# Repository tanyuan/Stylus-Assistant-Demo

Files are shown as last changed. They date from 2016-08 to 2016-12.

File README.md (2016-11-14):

# Stylus Assistant: Designing Dynamic Constraints for Facilitating Stylus Inputs on Portable Displays

## Project Introduction
This work, Stylus Assistant, proposed two designs of actuator array system, **DynaFrame** and **DynaBase**, to realize dynamic physical constraints on portable displays for facilitating stylus input.

## DynaFrame

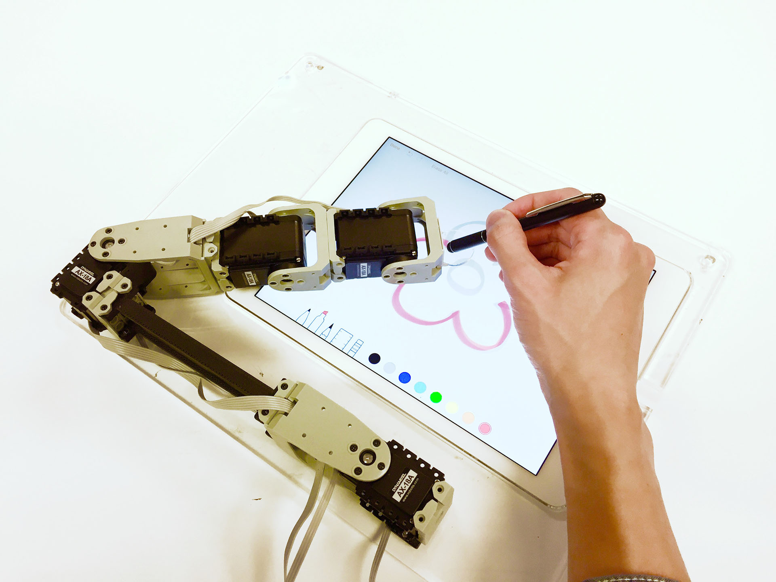
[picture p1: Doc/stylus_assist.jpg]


## User Interface

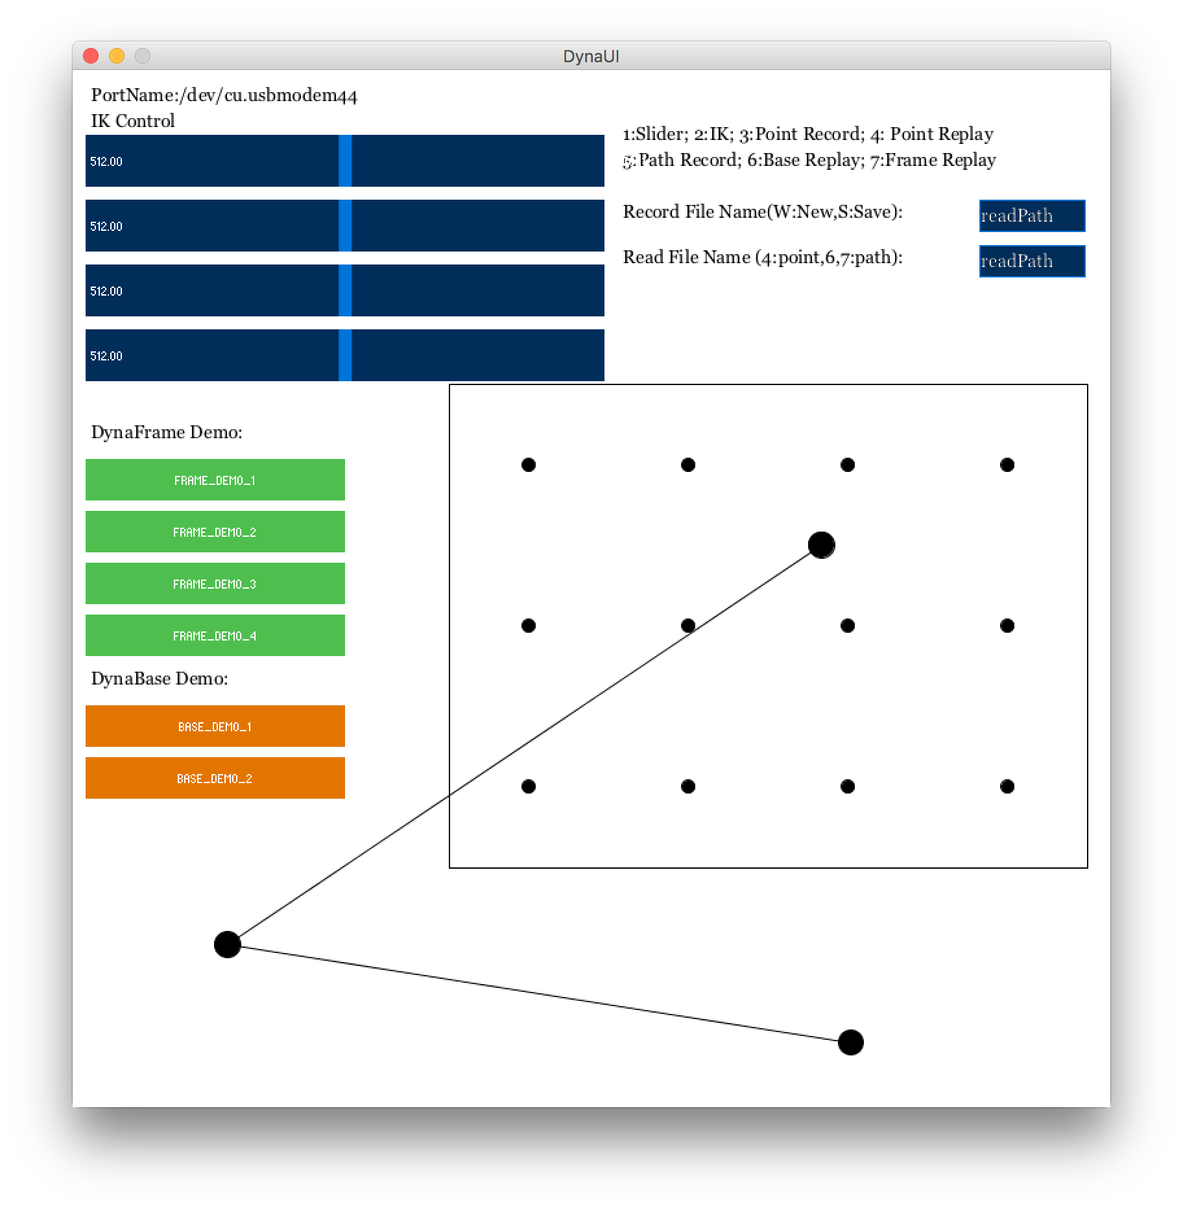
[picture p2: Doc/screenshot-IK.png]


## File Description
* **DynaArd** - Arduino Code
* **DynaUI** - Processing Code
* **Models** - SketchUp and Illustrator files
* **SetID** - Dynamixel AX-18A Motor ID Setting
* **Doc** - Documents

## Project Documents
* Original Version: [Google Doc](https://docs.google.com/document/d/1mkmDp4YyBh0SwKKhiSD5-HdVlsP8pnFafbvmv74smBk/edit?usp=sharing) / [PDF](Doc/StylusAssistantDocument.pdf)
* Demo Version: [Google Doc](https://docs.google.com/document/d/1DRZvKb9pZrIUMAFr76vTpBE7sWNrNrS9NaeW5d6-lQI/edit?usp=sharing)

## Author

Long-Fei Lin, National Taiwan University

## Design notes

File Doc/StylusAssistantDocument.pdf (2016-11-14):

# Stylus Assistant Instructions

## Modes

在硬體鏈接無誤后，Arduino的Code也上傳到Mega后，打開Processing。 這份Code包括7種不同的控制馬達的模式，通過按鍵盤上數字的1﹣7來切換：
1. Slider Control，左右移動滑塊可控制單個馬達，用以最初的Debug;
2. IK Control, 這時候按住滑鼠左鍵，移動滑鼠就可以控制馬達移動;
3. Points Record Control, 記錄單個點,一般用于實驗；
4. Points Replay Control, 回放單個點；
5. Path Record Control, 記錄畫筆的路徑；
6. DynaBase Path Replay, 用於DynaBase 路徑回放；
7. DynaFrame Path Replay, 用於Dyna Frame 路徑回放。

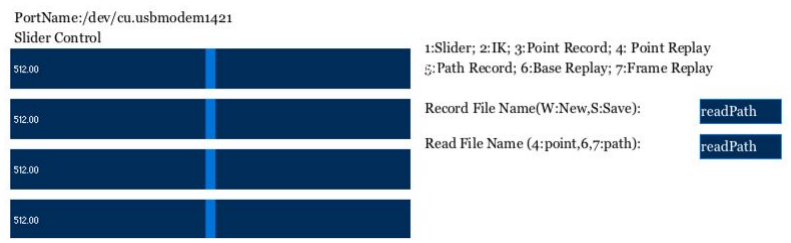
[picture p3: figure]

## Processing Setting

1. 首先確認Processing 的PortName為Arduino Mega (比如dev/cu.usbmodem1421)，否 則到Processing中的portName = Serial.list()[3] 中修改數字，數字參考Arduino菜單欄 Tools->Port， 從0開始數；
2. PortName 下方為7重模式的狀態欄，切換數字鍵1﹣7來更改；
3. 右邊兩個輸入框為文件名填寫，以保存與讀取相對應的路徑。

## Points Record and Replay

=== Points Record
1. 更改記錄文件的名稱 Record File Name；
2. 按數字‘3’，進入Points Record Mode；
3. 按‘w’新建一個一個txt檔案；
4. 點擊滑鼠到相對應的位置；按'n'記錄下一個點，重複該步驟；
5. 記錄結束后按's'保存文件，切記，否則文件為空。
=== Points Replay
1. 更改讀取文件的名稱Read File Name；
2. 按數字‘4’，進入Points Replay Mode；
3. 這時候馬達會直接開始跑到第一個點；
4. 按字母‘n’，可以走到下一個點；
5. 按字母’b’, 可以走回上一個點。

## Path Record and Replay

=== Path Record
1. 更改紀錄文件的名稱，Record File Name；
2. 按數字’5’, 進入Path Record Mode；
3. 按字母’w’，新建一個txt檔案；
4. 按住滑鼠左鍵，移動滑鼠來畫出所需要的路徑，在记录Frame的路徑都適合，每一個 筆劃結束和開始的時候，按住鼠標停頓1秒；
5. 畫完後按字母’s’，保存文件，切記，否則文件唯恐。
=== Points Replay
DynaBase與DynaFrame的回放操作步驟一致，但由於兩者的後3 4顆馬達的角度計算不同， 故回放模式不同，Base為6，Frame為7，不可混餚；
1. 更改回放文件的名稱，Read File Name;
2. 按下’6/7’後，開始回放剛才的路徑。

# Hardware Setting

## Reference

硬體的設置最早的參考是來源於這個鏈接，AX12A的原理與AX18A基本相同，這裡我們使用 的鏈接方式為Dynamixel Serial1
http://savageelectronics.blogspot.tw/2011/01/arduino-y-dynamixel-ax-12.html

## Hardware Lists

以下為物品清單，以及各個組件之間的連接方式，
如果是很多個馬達，就直接並聯馬達的pin腳。
- Arduino Mega 2560
- Dynamile AX18A
- Multiplexer 74LS241
- Resistance 10kΩ

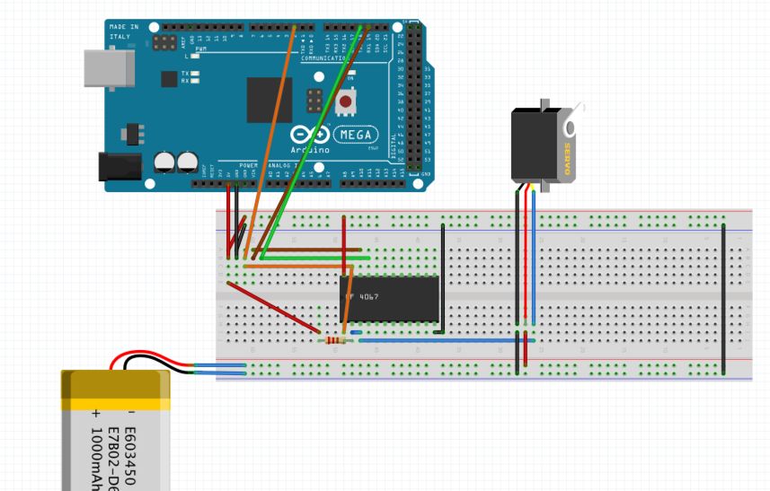
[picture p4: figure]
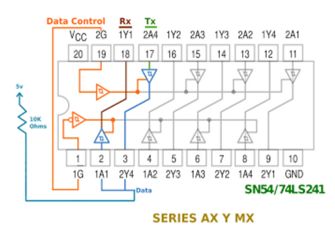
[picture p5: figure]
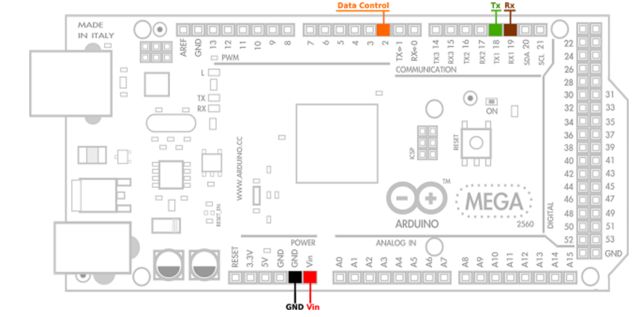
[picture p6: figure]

Multiplexer 74LS241 | Mega

# Software Setting

## Arduino

== Dynamixel Arduino Library Document http://austinlpalmer.com/Projects/Documentr/#/home
== Library Download, [DynamixelSerial1.zip] https://sourceforge.net/projects/dynamixelforarduino/files/?source=navbars

以下為Arduino控制Dyanmixel的Library，根據Document顯示，比較常用的幾個函數分別為
- setId (ID , newID )；因為會控制很多馬達，所以需要設置各個馬達的ID，出廠ID為1。 這裡需要注意的是，在為馬達設置完ID后，請再馬達上做上相對的記號，免得之後忘 記；
- ping(ID) 用來找馬達是否鏈接正確，1為找到，0為未找到；
- Dynamixel.moveSpeed(ID , Position, Speed) : ID為對應馬達的ID，Postion為馬達要 轉到的位置[0,1023]，Speed為馬達轉動的速度[0,1023];
- Dynamixel.move ( ID , Position) : ID為對應馬達的ID，Postion為馬達要轉到的位置 [0,1023]
- var = Dynamixel.readPosition(ID) ; 讀取馬達ID的當前位置

== Code Review
MOTORNUM 馬達的個數
motorRange[MOTORNUM][2] 馬達角度保護區間，放置數據傳輸錯誤，防止馬達角度超過一 定值，互相干擾卡在一起，保護馬達不會損壞
readEvent(Pos)：接受從Processing 那邊傳來的馬達角度
sendEvent(readPos): 將馬達當前的位置發送給Processing

## Processing

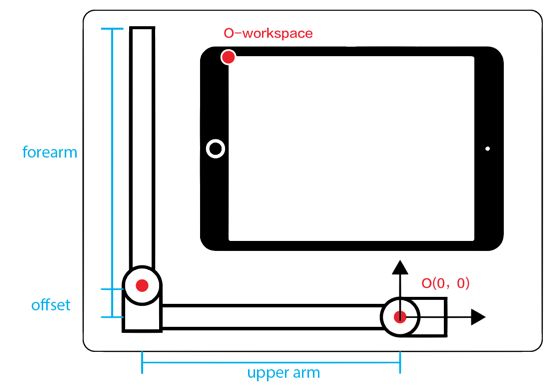
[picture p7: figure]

===Parameters Review
PVector screen = new PVector(19.7, 14.9); //螢幕的長寬長度 在計算IK的時候，會把Processing的座標系原點轉換到機械手臂根部，如圖O點，並且水平方 向做鏡像翻轉，從而得到新的座標系；
PVector wsOrig = new PVector(-12.4, 20.3); // workspace original (cm)
float uppL = 19.3; | //上臂的長度(upper arm)
float mdL = 2.55; | //中間的長度(offset)
float downL = 20.3; | //前臂的長度(forearm)
byte motorNum = 4; | //馬達個數，應該與Arduino一致
float cmTopx = 25; | //單位轉換 Cm to Px
PVector orignal = new PVector(600, 750); //新座標系原點在Processing座標系中的位置

===Fuctions Review

Processing 中分為7個主要的文檔，以控制不同的模塊：
- DyanUI為主函數；
- Gui 為Processing上面的UI；
- GuiScript 為Processing控制UI組件的函數，以及快捷鍵的控制；
- IKFuc 為IK計算過程中的函數；
- IKControl(x, y, upperArm, offset, foreArme)，輸入Processing內的座標系，得 出馬達1與馬達2的角度float[-300,300]
- angleMap，將角度轉化為馬達可以讀取的數值int[0,1023]
- TangentCalculate 用於計算Base的曲線切線角度與Frame的z軸高度；
- TangentAngle()，計算出DynaBase第三個馬達的角度值；
- AddZDimension()，插入出DynaFrame第三第四顆馬達的高度值
- TxtIO 為Txt文檔的讀取；
- serial_IO 為Processing與Arduino溝通的函數。

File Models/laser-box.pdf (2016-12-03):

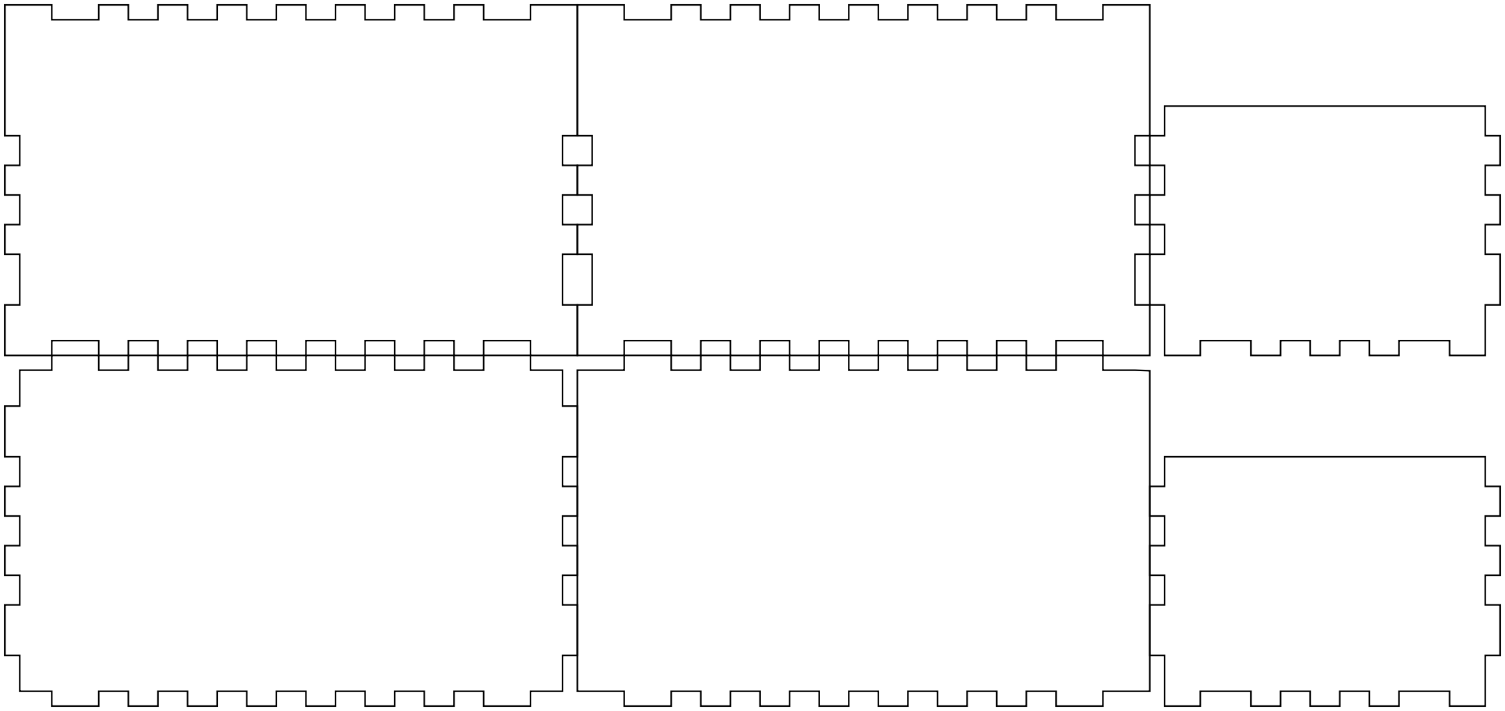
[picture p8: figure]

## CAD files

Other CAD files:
Models/Constraint_Connector.skp
Models/DynaBase_Rotator.skp
Models/Extender_117mm.skp
Models/Extender_80mm.skp
Models/Motor Base.skp

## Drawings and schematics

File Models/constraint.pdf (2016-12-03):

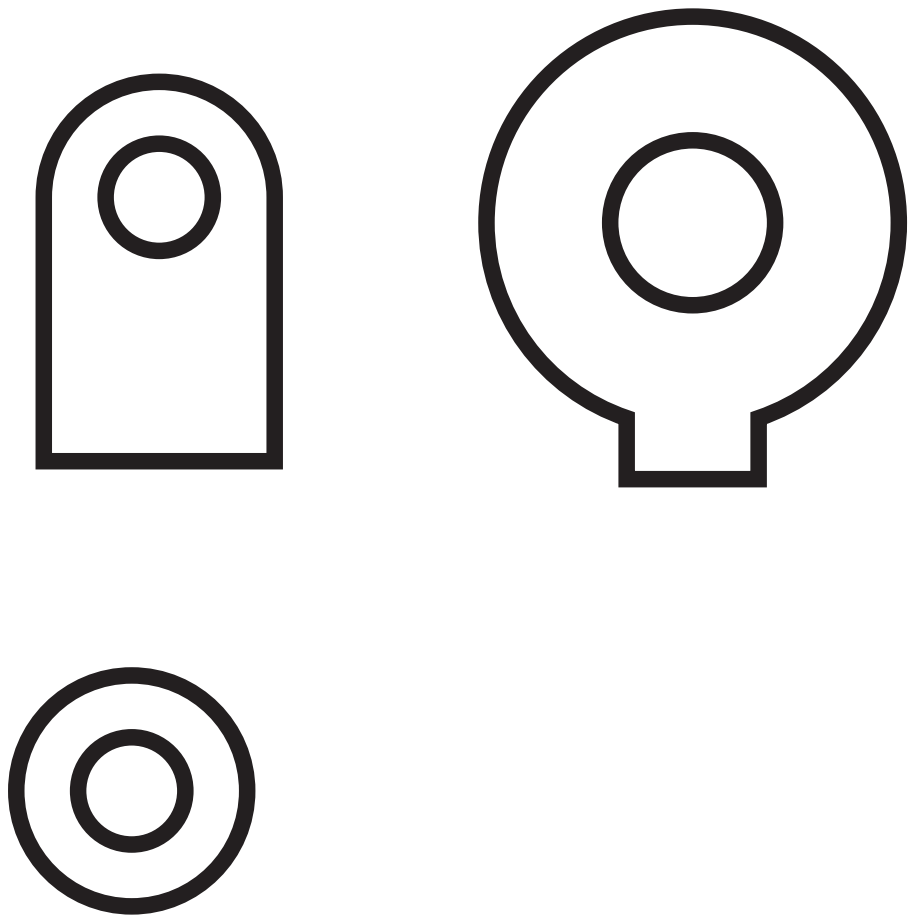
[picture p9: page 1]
Sumsung ：243.1 x 171.4 x 7.9 mm

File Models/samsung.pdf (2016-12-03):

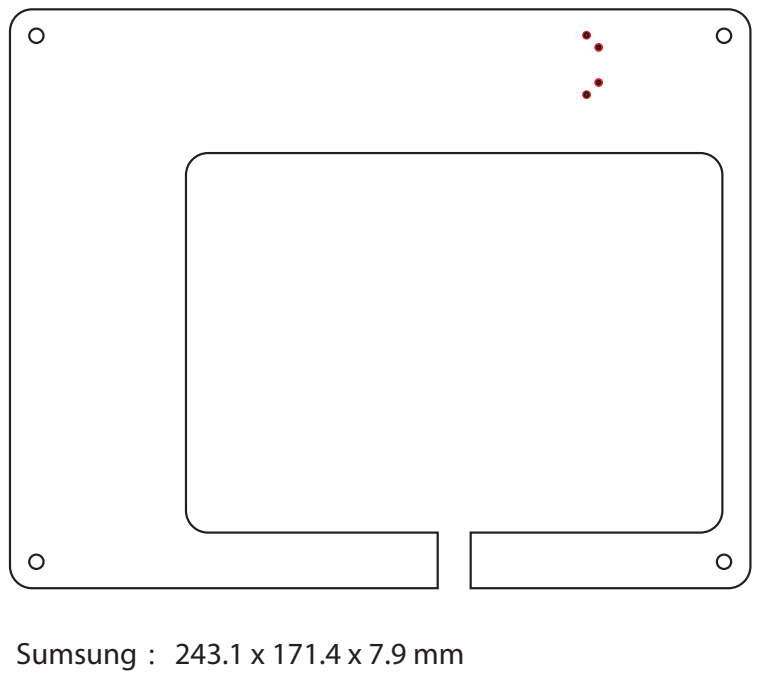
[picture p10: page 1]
Sumsung ：243.1 x 171.4 x 7.9 mm

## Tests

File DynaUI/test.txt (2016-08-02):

17.0,265.0,512,17.0,265.0,512,17.0,265.0,512,17.0,265.0,512,17.0,265.0,512,17.0,265.0,512,17.0,265.0,512,17.0,265.0,512,17.0,265.0,512,17.0,265.0,512,17.0,265.0,512,17.0,265.0,512,17.0,265.0,512,17.0,265.0,512,17.0,265.0,512,17.0,265.0,512,16.0,265.0,512,15.0,265.0,512,14.0,265.0,512,13.0,265.0,512,11.0,265.0,512,10.0,264.0,512,9.0,264.0,512,7.0,263.0,512,5.0,262.0,512,3.0,261.0,512,1.0,259.0,512,0.0,259.0,512,-2.0,259.0,512,-4.0,258.0,512,-5.0,258.0,512,-7.0,257.0,512,-11.0,256.0,512,-14.0,255.0,512,-16.0,254.0,512,-18.0,254.0,512,-20.0,254.0,512,-22.0,254.0,512,-26.0,254.0,512,-29.0,254.0,512,-32.0,254.0,512,-36.0,254.0,512,-39.0,254.0,512,-41.0,254.0,512,-45.0,254.0,512,-45.0,254.0,512,-45.0,254.0,512,-45.0,254.0,512,-45.0,254.0,512,-45.0,254.0,512,-45.0,254.0,512,-45.0,254.0,512,-45.0,254.0,512,-45.0,254.0,512,-45.0,254.0,512,-45.0,254.0,512,-45.0,254.0,512,-45.0,254.0,512,-45.0,254.0,512,-46.0,254.0,512,-52.0,248.0,512,-55.0,245.0,512,-57.0,242.0,512,-58.0,240.0,512,-61.0,239.0,512,-62.0,237.0,512,-64.0,236.0,512,-65.0,235.0,512,-66.0,233.0,512,-67.0,233.0,512,-68.0,232.0,512,-69.0,231.0,512,-71.0,229.0,512,-72.0,228.0,512,-72.0,228.0,512,-73.0,228.0,512,-74.0,227.0,512,-75.0,227.0,512,-75.0,227.0,512,-75.0,227.0,512,-75.0,227.0,512,-75.0,227.0,512,-75.0,227.0,512,-75.0,227.0,512,-76.0,228.0,512,-76.0,229.0,512,-76.0,231.0,512,-76.0,232.0,512,-76.0,234.0,512,-76.0,235.0,512,-78.0,237.0,512,-78.0,239.0,512,-78.0,241.0,512,-78.0,242.0,512,-78.0,245.0,512,-78.0,247.0,512,-78.0,248.0,512,-78.0,249.0,512,-78.0,250.0,512,-78.0,252.0,512,-76.0,254.0,512,-76.0,256.0,512,-76.0,258.0,512,-75.0,259.0,512,-75.0,261.0,512,-75.0,263.0,512,-75.0,265.0,512,-74.0,267.0,512,-74.0,270.0,512,-73.0,272.0,512,-73.0,272.0,512,-73.0,272.0,512,-73.0,272.0,512,-72.0,282.0,512,-72.0,285.0,512,-71.0,286.0,512,-71.0,288.0,512,-71.0,290.0,512,-70.0,292.0,512,-70.0,295.0,512,-69.0,297.0,512,-68.0,299.0,512,-67.0,302.0,512,-66.0,304.0,512,-65.0,307.0,512,-64.0,311.0,512,-63.0,312.0,512,-62.0,314.0,512,-62.0,316.0,512,-61.0,320.0,512,-60.0,323.0,512,-60.0,325.0,512,-59.0,327.0,512,-58.0,328.0,512,-58.0,331.0,512,-58.0,333.0,512,-57.0,335.0,512,-56.0,339.0,512,-55.0,343.0,512,-54.0,345.0,512,-54.0,346.0,512,-53.0,348.0,512,-52.0,350.0,512,-52.0,351.0,512,-51.0,353.0,512,-50.0,355.0,512,-49.0,357.0,512,-48.0,359.0,512,-47.0,362.0,512,-46.0,364.0,512,-45.0,367.0,512,-45.0,368.0,512,-45.0,369.0,512,-43.0,371.0,512,-42.0,374.0,512,-42.0,377.0,512,-41.0,378.0,512,-41.0,380.0,512,-40.0,382.0,512,-40.0,383.0,512,-39.0,384.0,512,-39.0,385.0,512,-39.0,386.0,512,-38.0,388.0,512,-37.0,389.0,512,-37.0,393.0,512,-37.0,394.0,512,-37.0,395.0,512,-36.0,395.0,512,-36.0,395.0,512,-36.0,395.0,512,-36.0,395.0,512,-36.0,395.0,512,-36.0,395.0,512,-36.0,395.0,512,-36.0,395.0,512,-36.0,395.0,512,-36.0,394.0,512,-36.0,393.0,512,-36.0,390.0,512,-37.0,387.0,512,-38.0,384.0,512,-40.0,380.0,512,-41.0,375.0,512,-43.0,371.0,512,-44.0,366.0,512,-45.0,360.0,512,-46.0,356.0,512,-48.0,350.0,512,-48.0,346.0,512,-50.0,342.0,512,-53.0,331.0,512,-55.0,324.0,512,-56.0,317.0,512,-57.0,311.0,512,-59.0,305.0,512,-60.0,299.0,512,-63.0,289.0,512,-63.0,289.0,512,-64.0,286.0,512,-66.0,276.0,512,-67.0,273.0,512,-67.0,270.0,512,-67.0,268.0,512,-67.0,265.0,512,-67.0,264.0,512,-67.0,259.0,512,-66.0,258.0,512,-66.0,258.0,512,-62.0,254.0,512,-60.0,251.0,512,-60.0,251.0,512,-58.0,249.0,512,-54.0,247.0,512,-51.0,245.0,512,-48.0,242.0,512,-44.0,240.0,512,-42.0,238.0,512,-36.0,235.0,512,-36.0,235.0,512,-29.0,233.0,512,-29.0,233.0,512,-26.0,232.0,512,-17.0,231.0,512,-13.0,231.0,512,-9.0,231.0,512,-5.0,231.0,512,0.0,231.0,512,4.0,232.0,512,9.0,233.0,512,13.0,234.0,512,18.0,236.0,512,23.0,239.0,512,28.0,241.0,512,37.0,247.0,512,40.0,249.0,512,45.0,254.0,512,47.0,256.0,512,49.0,258.0,512,51.0,261.0,512,53.0,264.0,512,54.0,267.0,512,55.0,272.0,512,57.0,275.0,512,58.0,279.0,512,59.0,284.0,512,59.0,292.0,512,59.0,296.0,512,59.0,299.0,512,58.0,306.0,512,58.0,306.0,512,55.0,311.0,512,52.0,316.0,512,49.0,321.0,512,46.0,328.0,512,43.0,332.0,512,40.0,337.0,512,37.0,341.0,512,31.0,349.0,512,28.0,353.0,512,24.0,356.0,512,24.0,356.0,512,15.0,362.0,512,12.0,364.0,512,8.0,365.0,512,3.0,367.0,512,0.0,368.0,512,-3.0,368.0,512,-6.0,369.0,512,-6.0,369.0,512,-13.0,369.0,512,-15.0,369.0,512,-15.0,369.0,512,-20.0,369.0,512,-26.0,369.0,512,-29.0,369.0,512,-30.0,369.0,512,-31.0,369.0,512,-31.0,369.0,512,-31.0,369.0,512,-31.0,369.0,512,-31.0,369.0,512,-31.0,369.0,512,-31.0,369.0,512,-31.0,369.0,512,-31.0,369.0,512,-31.0,369.0,512,-31.0,369.0,512,-31.0,369.0,512,-31.0,369.0,512,-31.0,369.0,512,-31.0,369.0,512,-31.0,369.0,512,-31.0,369.0,512,-31.0,369.0,512,-31.0,369.0,512,-30.0,369.0,512,-30.0,369.0,512,-30.0,369.0,512,-30.0,369.0,512,-30.0,369.0,512,-30.0,369.0,512,-29.0,369.0,512,-29.0,369.0,512,-29.0,369.0,512,-29.0,369.0,512,-19.0,369.0,512,-15.0,369.0,512,-5.0,367.0,512,-1.0,366.0,512,-1.0,366.0,512,5.0,364.0,512,9.0,364.0,512,19.0,362.0,512,30.0,358.0,512,36.0,356.0,512,36.0,356.0,512,36.0,356.0,512,60.0,347.0,512,68.0,344.0,512,68.0,344.0,512,80.0,338.0,512,86.0,334.0,512,99.0,326.0,512,103.0,323.0,512,111.0,314.0,512,115.0,310.0,512,117.0,307.0,512,118.0,304.0,512,121.0,297.0,512,121.0,297.0,512,123.0,295.0,512,124.0,291.0,512,124.0,290.0,512,124.0,290.0,512,124.0,289.0,512,123.0,288.0,512,121.0,287.0,512,119.0,287.0,512,118.0,286.0,512,117.0,285.0,512,116.0,285.0,512,115.0,285.0,512,114.0,284.0,512,114.0,284.0,512,113.0,284.0,512,113.0,284.0,512,113.0,284.0,512,113.0,284.0,512,113.0,284.0,512,110.0,284.0,512,109.0,284.0,512,109.0,284.0,512,105.0,284.0,512,104.0,284.0,512,101.0,284.0,512,99.0,284.0,512,93.0,284.0,512,93.0,284.0,512,87.0,284.0,512,85.0,284.0,512,78.0,284.0,512,74.0,284.0,512,70.0,284.0,522,67.0,284.0,522,64.0,285.0,522,62.0,286.0,522,60.0,286.0,522,56.0,288.0,522,54.0,288.0,522,50.0,290.0,522,47.0,291.0,522,44.0,292.0,522,38.0,293.0,522,35.0,295.0,532,29.0,297.0,532,28.0,298.0,532,27.0,299.0,532,27.0,299.0,532,27.0,299.0,532,27.0,299.0,532,27.0,299.0,532,27.0,299.0,532,27.0,307.0,542,27.0,311.0,542,27.0,313.0,542,27.0,316.0,542,28.0,320.0,542,29.0,321.0,542,29.0,323.0,542,29.0,323.0,542,32.0,328.0,542,34.0,330.0,542,35.0,332.0,542,37.0,334.0,542,38.0,336.0,542,42.0,338.0,542,45.0,341.0,552,48.0,343.0,552,52.0,346.0,552,58.0,348.0,552,65.0,349.0,552,74.0,350.0,552,85.0,351.0,552,97.0,353.0,552,110.0,353.0,552,123.0,354.0,552,131.0,354.0,552,137.0,354.0,552,142.0,354.0,552,143.0,354.0,552,144.0,354.0,552,145.0,354.0,552,145.0,354.0,552,146.0,354.0,552,148.0,354.0,552,149.0,354.0,552,151.0,354.0,552,152.0,354.0,552,153.0,354.0,542,155.0,354.0,542,155.0,354.0,542,156.0,354.0,542,156.0,354.0,542,157.0,354.0,542,157.0,354.0,542,157.0,354.0,542,157.0,354.0,542,157.0,354.0,542,157.0,354.0,542,157.0,354.0,542,157.0,354.0,542,157.0,354.0,542,157.0,354.0,532,157.0,354.0,532,157.0,354.0,532,157.0,354.0,532,157.0,354.0,532,158.0,355.0,532,160.0,356.0,532,162.0,356.0,532,167.0,358.0,532,168.0,359.0,532,170.0,359.0,532,171.0,359.0,532,172.0,360.0,532,173.0,360.0,532,173.0,360.0,532,173.0,360.0,532,173.0,360.0,532,173.0,360.0,532,173.0,360.0,522,173.0,360.0,522,173.0,360.0,522,174.0,361.0,522,174.0,361.0,522,174.0,362.0,522,175.0,363.0,522,176.0,364.0,522,177.0,367.0,522,177.0,367.0,522,177.0,367.0,522,177.0,368.0,522,177.0,368.0,522,177.0,368.0,522,177.0,368.0,522,177.0,368.0,522,177.0,368.0,522,177.0,368.0,522,177.0,368.0,522,177.0,368.0,522,177.0,368.0,522,177.0,368.0,522,177.0,368.0,522,177.0,368.0,522,177.0,368.0,522,177.0,368.0,522,177.0,368.0,522,177.0,368.0,522,177.0,368.0,522,177.0,368.0,522,177.0,368.0,522,177.0,368.0,522,177.0,368.0,522,177.0,368.0,522,177.0,368.0,522,177.0,368.0,522,177.0,368.0,522,177.0,368.0,522,177.0,368.0,522,177.0,368.0,522,177.0,368.0,522,177.0,368.0,522,177.0,368.0,522,177.0,368.0,522,177.0,368.0,522,177.0,368.0,522,177.0,368.0,522,177.0,368.0,522,177.0,368.0,522,177.0,368.0,512,177.0,368.0,512,177.0,368.0,512,177.0,368.0,512,177.0,368.0,512,177.0,368.0,512,177.0,368.0,512,177.0,368.0,512,177.0,368.0,512,177.0,368.0,512,177.0,368.0,512,177.0,368.0,502,177.0,368.0,502,177.0,368.0,502,177.0,368.0,502,177.0,368.0,502,177.0,368.0,502,177.0,368.0,502,177.0,368.0,502,177.0,368.0,502,177.0,368.0,502,177.0,368.0,502,177.0,368.0,502,

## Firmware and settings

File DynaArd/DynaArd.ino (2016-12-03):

/**
   For Dynamixel Control
   by andy, 2016
   Library:
  http://austinlpalmer.com/Projects/Documentr/#/home

*/
#define MOTORNUM 4


#include <DynamixelSerial1.h>

int pos[MOTORNUM];
int prePos[MOTORNUM];
int readPos[MOTORNUM];
//From root to end,protect motor from damage
int motorRange[MOTORNUM][2]  = {
  {100, 900},
  {230, 600},
  {0, 1023},
  {0, 1023},
  //{500,600},
  //{600,800},
  //{400, 768},
  //{300,550},
};



void setup() {
  // Inicialize the servo at 1Mbps and Pin Control 2
  Dynamixel.begin(1000000, 2);
  Serial.begin(9600);
  delay(1000);
  for (int i = 0; i < MOTORNUM; i++) {
    pos[i] = 512;
    Dynamixel.moveSpeed(i + 1, pos[i], 200);
  }
  delay(1000);
}

void loop() {
  readEvent(pos);

  if (!arrayCompare(pos, prePos)) {
    //sendEvent(readPos);
    arrayCopy(pos, prePos);
  }

  //  Dynamixel.moveSpeed(1, angleProtect(0, pos[0]), 200);
  Dynamixel.moveSpeed(1, angleProtect(0, angleProtect(0, pos[0])), 100);
  Dynamixel.moveSpeed(2, angleProtect(1, angleProtect(1, pos[1])), 100);
  Dynamixel.moveSpeed(3, angleProtect(2, angleProtect(2, pos[2])), 200);
  Dynamixel.moveSpeed(4, angleProtect(3, angleProtect(3, 1020 - pos[2])), 200);

  //    readPos[0] = Dynamixel.readPosition(1);
  //    readPos[1] = Dynamixel.readPosition(2);
  //   readPos[2] = Dynamixel.readPosition(3);
  //      readPos[3] =Dynamixel.readPosition(4);
}


int angleProtect(int id, int angle) {
  if (angle < motorRange[id][0]) {
    angle = motorRange[id][0];
  } else if (angle > motorRange[id][1]) {
    angle = motorRange[id][1];
  }
  return angle;
}


boolean arrayCompare(int a1[MOTORNUM] , int a2[MOTORNUM] ) {
  for (int i = 0; i < MOTORNUM; i++) {
    if (a1[i] != a2[i])
      return false;
  }
  return true;
}

void arrayCopy(int a1[MOTORNUM] , int a2[MOTORNUM]) {
  for (int i = 0; i < MOTORNUM; i++) {
    a2[i] = a1[i];
  }
}

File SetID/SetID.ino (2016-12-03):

/* Sweep
  by BARRAGAN <http://barraganstudio.com>
  This example code is in the public domain.

  modified 8 Nov 2013
  by Scott Fitzgerald
  http://www.arduino.cc/en/Tutorial/Sweep
*/
#define MOTORNUM 4


#include <Servo.h>
#include <DynamixelSerial1.h>
int oldID = 1;
int newID = 3;
int pin = 0;

Servo myservo[MOTORNUM];  // create servo object to control a servo
int pos[MOTORNUM];
int readPos[MOTORNUM];
void setup() {
  // Inicialize the servo at 1Mbps and Pin Control 2
  Dynamixel.begin(1000000, 2);
  Serial.begin(9600);
  delay(1000);
  for (int i = 0; i < MOTORNUM; i++) {
    //myservo[i].attach(i + 2); //servo motors begin form pin2
    pos[i] = 160;
  }
//  Dynamixel.setID (1, 3) ;
  //Dynamixel.reset (3) ;
}

void loop() {
  if (pin < 100) {
    Serial.print("-------:");
    Serial.println(pin);
    Serial.println( Dynamixel.ping (pin)) ;
    Serial.println( Dynamixel.ping (pin)) ;
    Serial.println( Dynamixel.ping (pin)) ;
    Serial.println( Dynamixel.ping (pin)) ;
    Serial.println( Dynamixel.ping (pin)) ;
    Serial.println( Dynamixel.ping (pin)) ;
    Serial.println( Dynamixel.ping (pin)) ;
    Serial.println( Dynamixel.ping (pin)) ;
  }
  pin = pin + 1;
  //  delay(1000);
  //  Dynamixel.move(5, 100);
  //  delay(100);
  //  Dynamixel.move(5, 200);
  //  delay(100);
  //Serial.println( Dynamixel.ping (1)) ;
  delay(1000);
  //  Dynamixel.move(2, 512);
  //  delay(1000);
  //  Dynamixel.move(2, 0);
  //  delay(1000);
  // Serial.println( Dynamixel.ping (4)) ;
  // Serial.println( Dynamixel.ping (3)) ;
  //  Serial.println( Dynamixel.ping (1)) ;
  // Dynamixel.move(1, 512);
  //  delay(5);
  //  Dynamixel.move(2, 400);
  //  delay(5);
  //  Dynamixel.move(3, 400);
  //  delay(5);
  //  Dynamixel.move(4, 400);
  //  delay(3000);
  //  Dynamixel.move(1, 1023);
  //  delay(5);
  //  Dynamixel.move(2, 450);
  //  delay(5);
  //  Dynamixel.move(3, 800);
  //  delay(5);
  //  Dynamixel.move(1, 410);
  // Dynamixel.move(4, 800);
  //delay(1000);



}

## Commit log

2016-08-03 UI calibration
2016-08-04 IK calibration
2016-08-04 发送的稳定版本
2016-08-04 add sample points
2016-08-04 sending data from arduino to processing
2016-08-07 增加尺子的角度，目前为稳定版本
2016-08-07 hhy之前的版本
2016-08-13 Motor Calibration Setting
2016-08-13 ipad calibration data
    [ipad.xlsx]
2016-08-13 DynaUI Update
    [ipad.xlsx]
2016-11-14 Add demo buttons
2016-11-15 Base demo button
